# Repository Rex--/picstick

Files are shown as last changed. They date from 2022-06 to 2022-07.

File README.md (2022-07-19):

# picstick

An AVR based programming adapter for PIC microcontrollers that use Microchip's
low-voltage In Circuit Serial Programming (ICSP) interface.
It decodes the flash data sent from a [host application](https://github.com/rex--/picchick)
and programs it into the memory of a PIC microcontroller.



The picstick can be plugged directly into a USB A port. It provides a 3x2 pin
header that breaks out the needed pins for ICSP, and +3.3V and GND. 

## Hardware
The hardware is based around an ATtiny44. Communication with the host PC is done
using a CH340E USB-to-UART bridge.

## Firmware
While the ATtiny44 has no hardware UART, it does have the Universal Serial
Interface(USI). This is leveraged to provide a faster and more compact software
UART. Because of this, the firmware will only run on AVR devices with a USI.

The firmware is designed to be able to run
with the internal 8MHz oscillator of an attiny44V. If the 8MHz oscillator is
used, the max baud rate is 76800. While the attiny44V is only specced to run on
an external crystal at a maximum of 8MHz @ 3.3v, succes has been found with a
crystal running at 16MHz @ 3.3v. This gives a max baud rate of 115200+.

### Building

#### Requirements
- make
- avr-gcc
- avrdude

#### Makefile Commands
Compilation is done with the make utility:
```sh
make [fw]       # Build firmware with settings defined in Makefile.
make flash       # Flash firmware using avrdude, building if neccessary.
make fuses      # Burn fuses as defined in the Makefile using avrdude.
make clean      # Remove built firmware files.
make fclean     # Remove all files and folders created.
```

Build firmware, flash, and set fuses:
```
make flash fuses
```

### Configuration

Currently, the configuration is spread out amoung several files:
- uuart.h - UART baudrate, USI serial library configuration.
- icsp.h - Pins to use for ICSP interface.
- Makefile - Oscillator frequency configuration.

**8Mhz @ 76800 bauds - Internal Oscillator**\
_L: E2 &nbsp;&nbsp; H: DF &nbsp;&nbsp; E: FF_\
This is the default configuration the firmware builds with. It does not require
any additional external components.

**8MHz @ 76800 bauds - External Crystal**\
_L: FD &nbsp;&nbsp; H: DF &nbsp;&nbsp; E: FF_\

**16MHz @ 115200 bauds - External Crystal**\
_L: FF &nbsp;&nbsp; H: DF &nbsp;&nbsp; E: FF_\
This configuration isnt officially supported by the ATtiny44V, but it seems to
work just fine.

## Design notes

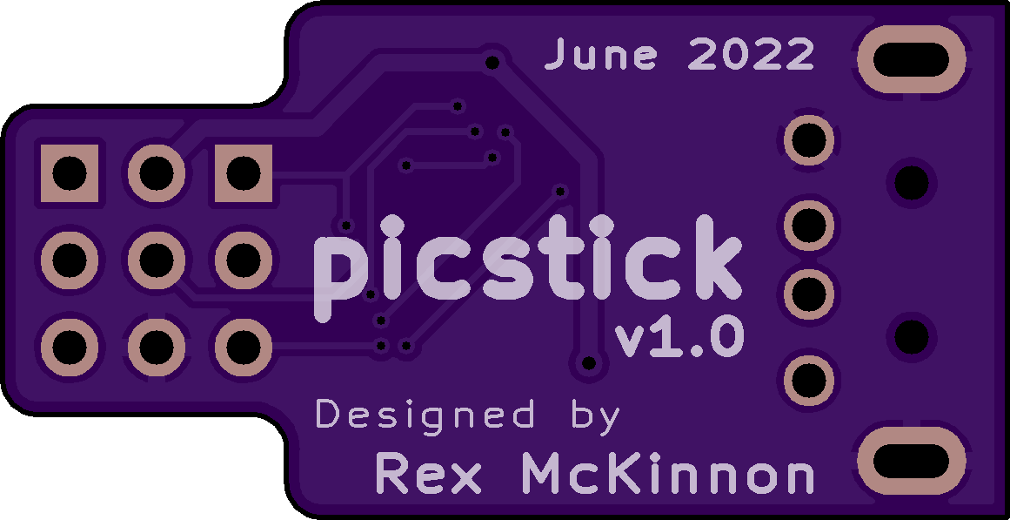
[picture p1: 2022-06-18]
docs/pcb-bottom-v1_0.png

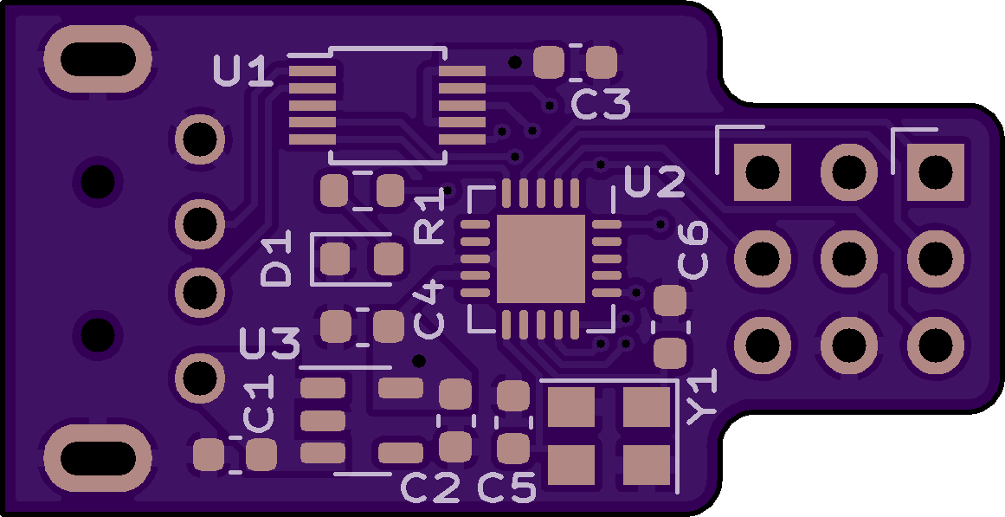
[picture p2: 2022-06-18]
docs/pcb-top-v1_0.png

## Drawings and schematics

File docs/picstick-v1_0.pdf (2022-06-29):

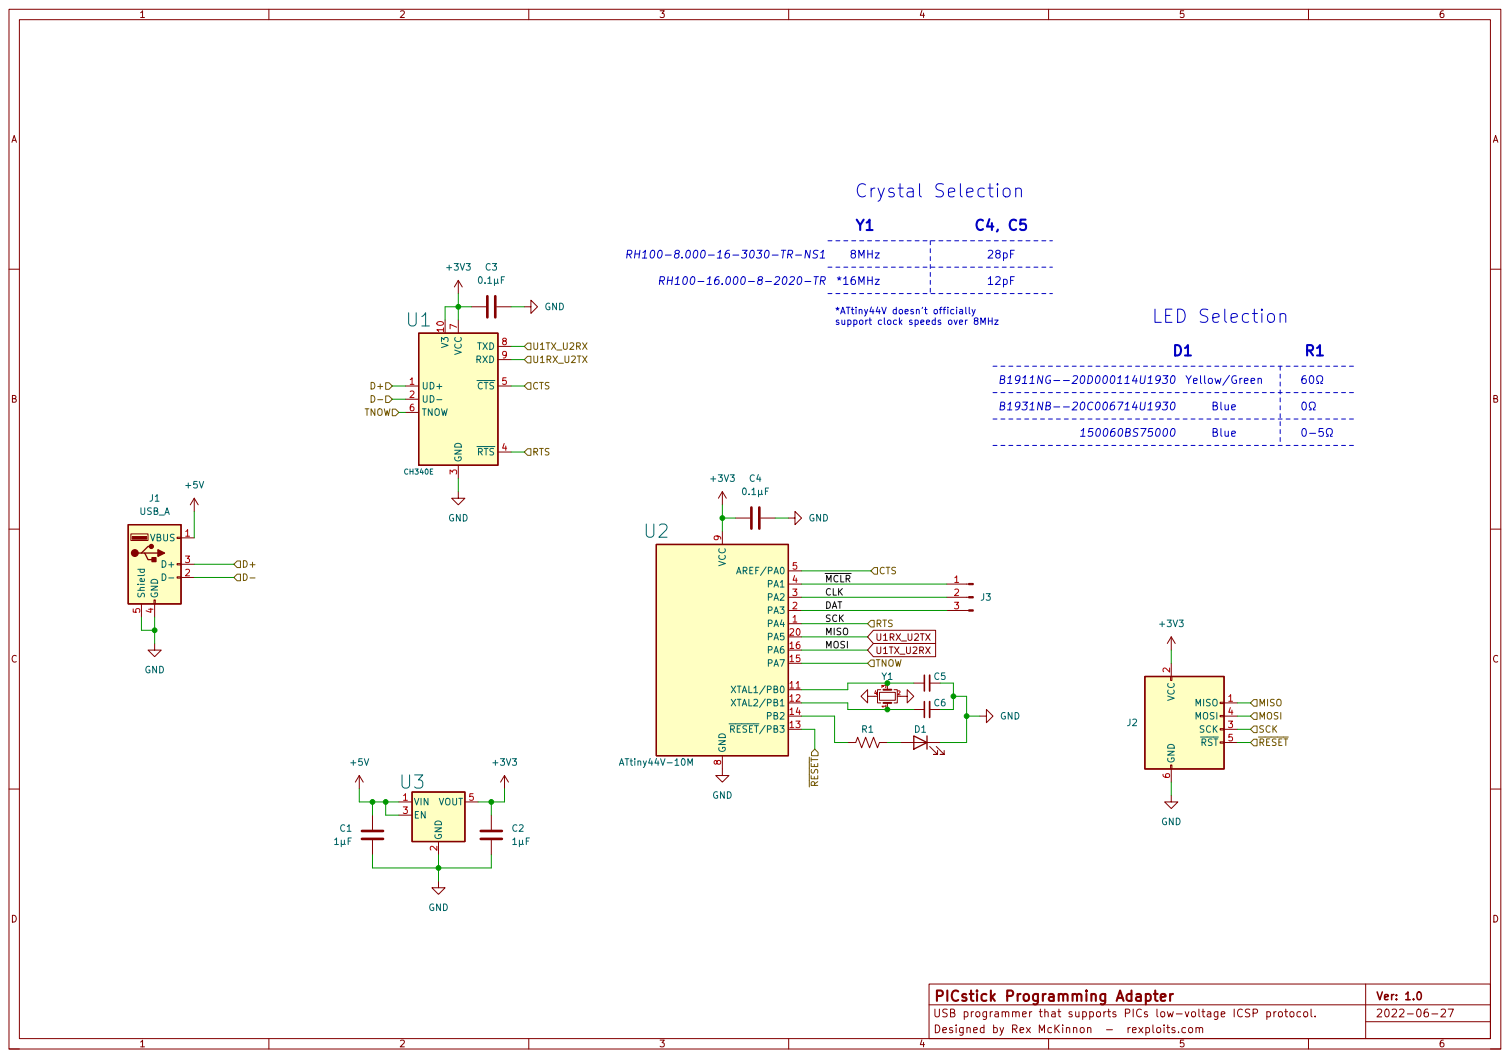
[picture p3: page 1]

support clock speeds over 8MHz RH100-8.000-16-3030-TR-NS1

3 ~{RTS} 4 ~{CTS} 5 TNOW 6 VCC

2 SCK 3 MOSI 4 ~{RST} 5 GND

D Designed by Rex McKinnon - rexploits.com

2022-06-27 PICstick Programming Adapter
USB programmer that supports PICs low-voltage ICSP protocol.

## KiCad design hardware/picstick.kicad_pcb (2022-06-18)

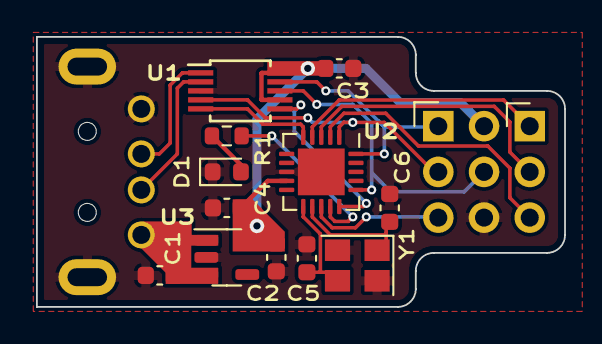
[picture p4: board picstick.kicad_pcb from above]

Board: 2 copper layers, 29.3 x 15.0 mm, 15 parts (0 on the bottom side), 18 nets.

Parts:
C1, C2: 1µF; C_0603_1608Metric
C3, C4: 0.1µF; C_0603_1608Metric
C5, C6: TBD; C_0603_1608Metric
D1: STATUS; LED_0603_1608Metric
J1: USB_A; UP2-AH-1-TH
J2: AVR-ISP-6; PinHeader_2x03_P2.54mm_Vertical
J3: Conn_01x03_Male; PinHeader_1x03_P2.54mm_Horizontal
R1: TBD; R_0603_1608Metric
U1: CH340E; MSOP-10_3x3mm_P0.5mm
U2: ATtiny44V-10M; QFN-20-1EP_4x4mm_P0.5mm_EP2.6x2.6mm
U3: MCP1801T-3302I/OT; SOT-23-5
Y1: TBD; Crystal_SMD_3225-4Pin_3.2x2.5mm

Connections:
+3V3: C2.1, C3.1, C4.1, J2.2 (VCC), U1.7 (VCC), U1.10 (V3), U2.9 (VCC), U3.5 (VOUT)
+5V: C1.1, J1.1 (VBUS), U3.1 (VIN), U3.3 (EN)
/CTS: U1.5 (~CTS), U2.5 (AREF/PA0)
/D+: J1.3 (D+), U1.1 (UD+)
/D-: J1.2 (D-), U1.2 (UD-)
/RTS: J2.3 (SCK), U1.4 (~RTS), U2.1 (PA4)
/TNOW: U1.6 (TNOW), U2.15 (PA7)
/~RESET: J2.5 (~RST), U2.13 (~RESET/PB3)
CLK: J3.2, U2.3 (PA2)
DAT: J3.3, U2.2 (PA3)
GND: C1.2, C2.2, C3.2, C4.2, C5.2, C6.2, D1.1 (K), J1.4 (GND), J1.5 (Shield), J2.6 (GND), U1.3 (GND), U2.8 (GND), U2.21 (GND), U3.2 (GND), Y1.2, Y1.4
unnamed: C5.1, U2.11 (XTAL1/PB0), Y1.3
unnamed: C6.1, U2.12 (XTAL2/PB1), Y1.1
unnamed: D1.2 (A), R1.2
unnamed: R1.1, U2.14 (PB2)
U1RX_U2TX: J2.1 (MISO), U1.9 (RXD), U2.20 (PA5)
U1TX_U2RX: J2.4 (MOSI), U1.8 (TXD), U2.16 (PA6)
~MCLR: J3.1, U2.4 (PA1)

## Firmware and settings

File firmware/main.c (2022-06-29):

/** @file main.c
 * 
 * picstick - A usb programmer for PICs that use
 * Microchip's In Circuit Serial Programming(ICSP) interface.
 * 
*/

#include <avr/io.h>
#include <avr/interrupt.h>
#include <util/delay.h>

#include "uuart.h"
#include "icsp.h"
#include "commands.h"


int
main (void)
{
    uuart_init();
    icsp_init();

    GIMSK |=  (1<<PCIE);		   // Enable pin change interrupt
    PCMSK |=  (1<<PCINT6);		   // Enable pin change interrupt for PA6
    sei();

    DDRB |= (1 << 2);   // LED pin output

    for (;;)
    {
        if (uuart_rx_data_available())
        {
            PORTB |= (1 << 2);
            handle_command();
            PORTB &= ~(1 << 2);
        }
    }
}

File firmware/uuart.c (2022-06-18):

/**
 * @file USI_UART.c
 * This module contains the definitions and functions necessary to
 * implements a HW UART on a ATtiny using its Universal Serial Interface (USI).
 */
#include <avr/io.h>			// uController specific registers
#include <avr/interrupt.h>
#include <stdlib.h>			// for itoa() function
//#include <util/delay.h>		// for debugging main()


#include "uuart.h"


/* Static Variables */
static unsigned char          uuart_rx_buf[UART_RX_BUFFER_SIZE];
static volatile unsigned char uuart_rx_head;
static volatile unsigned char uuart_rx_tail;

static unsigned char          uuart_tx_buf[UART_TX_BUFFER_SIZE];
static volatile unsigned char uuart_tx_head;
static volatile unsigned char uuart_tx_tail;
static volatile unsigned char uuart_tx_data;


// Status byte holding flag definition, initialized to 0
static volatile union uuart_status {
    unsigned char status;
    struct {
        unsigned char ongoing_Transmission_From_Buffer:1;
        unsigned char ongoing_Transmission_Of_Package:1;
        unsigned char ongoing_Reception_Of_Package:1;
        unsigned char reception_Buffer_Overflow:1;
        unsigned char flag4:1;
        unsigned char flag5:1;
        unsigned char flag6:1;
        unsigned char flag7:1;
    };
} uuart_status = {0};

/** Usi Uart functions **/

/*
 * Note that when the USI DO pin is configured as output, it is always
 * connected to the USIDR and takes on the value of the MSB.  Thus, when the
 * USIDR is not configured as a transmitter, the DO pin has to be forced to
 * a logical high in order to conform to the UART standard high-state idle
 * condition.  This state is implemented by configuring the DO pin as input
 * and then applying the internal pull-up resistors.
 */
void uuart_init(void) {
	// force the DO pin to the UART idle state (high)
    USI_DDR  &= ~((1<<USI_DI_PIN)|(1<<USI_DO_PIN));	// configure both as input
    USI_OUTPUT |= (1<<USI_DI_PIN)|(1<<USI_DO_PIN);	// Enable pull ups on both
    uuart_flush_buffers();				// set buffers at their beginnings
}

/**
 * Reverses the order of bits in a byte. (i.e. MSB is swapped with LSB, etc.)
 * @param x the byte whose bits need to be reversed: unsigned char
 * @return a byte with bits reversed in the same variable: unsigned char
 */
unsigned char Bit_Reverse( unsigned char x ) {
    x = ((x >> 1) & 0x55) | ((x << 1) & 0xaa);
    x = ((x >> 2) & 0x33) | ((x << 2) & 0xcc);
    x = ((x >> 4) & 0x0f) | ((x << 4) & 0xf0);
    return x;    
}

/*
 * Flush the UART buffers.
 * @param void
 * @return void
 */
void uuart_flush_buffers( void ) {
    uuart_rx_tail = 0;
    uuart_rx_head = 0;
    uuart_tx_tail = 0;
    uuart_tx_head = 0;
}

/*
 * Initialise USI for UART transmission.
 * @param void
 * @return void
 */
void uuart_tx_init( void )
{
    cli();									// disable all interrupts

    TCNT0  = 0x00;
    TIFR  |= (1<<TOV0);                     // Clear Timer0 OVF interrupt flag
    TIMSK |= (1<<TOIE0);                    // Enable Timer0 OVF interrupt
	TCCR0B |= (PRESCALECMD); 				/* Set prescaler to /8, start Timer0
						CS00 and CS02 need to be zero (default at startup) */
	GTCCR |= (1<<PSR0);						// start prescaller at 0
    USICR  = (0<<USISIE)|(1<<USIOIE)|       // Enable USI Counter OVF interrupt.
             (0<<USIWM1)|(1<<USIWM0)|       // Select Three Wire mode.
             // Select Timer0 overflow as USI Clock source.
             (0<<USICS1)|(1<<USICS0)|(0<<USICLK)|
             (0<<USITC);                                           
             
    USISR  = 0xF0 |              // Clear all USI interrupt flags.
             0x0F;				 /* Preload the USI counter to generate
             	 	 	 	 	 	 	 	   interrupt at first USI clock */
    USIDR  = 0xFF;               // Make sure MSB is '1' before enabling USI_DO
    USI_DDR  |= (1<<USI_DO_PIN); // Configure USI_DO as output
                  
    uuart_status.ongoing_Transmission_From_Buffer = TRUE;
                  
    sei();								// enable all interrupts
}


/**
 * Puts data in the transmission buffer, after reversing the bits in the byte.
 * Initiates the transmission routines if not already started.
 * @param data a byte to be transmitted: unsigned char
 * @return void
 */
void uuart_tx_byte( unsigned char data ) {
    unsigned char tmphead;
    // Calculate buffer index and if necessary, roll over at upper bound
    tmphead = (uuart_tx_head + 1) & UART_TX_BUFFER_MASK;
    while ( tmphead == uuart_tx_tail );          // Wait for free space in buffer
    uuart_tx_buf[tmphead] = Bit_Reverse(data);   /* Reverse the order of the bits
                                  in the data byte and store data in buffer */
    uuart_tx_head = tmphead;                     // Store new index.
    // Start transmission from buffer (if not already started).
    if (!(uuart_status.ongoing_Transmission_From_Buffer)) {
        while (uuart_status.ongoing_Reception_Of_Package); /* Wait for USI
                                             to finish reading incoming data */
        uuart_tx_init();              
    }
}

void
uuart_tx_bytes (unsigned char *buf, unsigned char len)
{
    for (int i = 0; i < len; i++)
    {
        uuart_tx_byte(buf[i]);
    }
}

/**
 * Returns a byte from the receive buffer. Waits if buffer is empty.
 * @param void
 * @return data from the buffer: unsigned char
 */
unsigned char uuart_rx_byte( void ) {
    unsigned char tmptail;
        
    while ( uuart_rx_head == uuart_rx_tail );             // Wait for incoming data
    // Calculate buffer index and if necessary, roll over at upper bound
    tmptail = ( uuart_rx_tail + 1 ) & UART_RX_BUFFER_MASK;
    uuart_rx_tail = tmptail;                                // Store new index 
    return Bit_Reverse(uuart_rx_buf[tmptail]);              /* Reverse the order
    	of the bits in the data byte before it returns data from the buffer */
}


unsigned char
uuart_rx_bytes (unsigned char *buf, unsigned char len)
{

    unsigned char bytes_read = 0;

    while (bytes_read < len)
    {
        buf[bytes_read++] = uuart_rx_byte();
    }
    return bytes_read;
}

unsigned char
uuart_rx_bytes_until (unsigned char sep, unsigned char *buf, unsigned char len)
{
    unsigned char bytes_read = 0;
    unsigned char read_byte;

    while (bytes_read < len)
    {
        read_byte = uuart_rx_byte();
        if (read_byte == sep)
        {
            return bytes_read;
        }
        buf[bytes_read++] = read_byte;
    }

    return len;
}

/**
 * Check if there is data in the receive buffer.
 * @return  0 (FALSE) if the receive buffer is empty: unsigned char
 */
unsigned char uuart_rx_data_available( void ) {
    return ( uuart_rx_head != uuart_rx_tail );
}


// ********** Interrupt Handlers ********** //
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

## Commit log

2022-06-18 Added hardware version 1.0. Boards are untested.
    [picstick-B_Cu.gbr, picstick-B_Mask.gbr, picstick-B_Paste.gbr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]
2022-06-24 Fixed a bug when writing to address x3A00. Also some slight speed improvements when writing rows.
    [commands.c]
2022-06-29 Updated schematic with crystal and LED component values.
    [picstick.kicad_sch]
2022-06-29 Fixed a bug when reading NVM from PIC. Updated firmware to work on picstick board.
    [icsp.h, main.c, uuart.h]
